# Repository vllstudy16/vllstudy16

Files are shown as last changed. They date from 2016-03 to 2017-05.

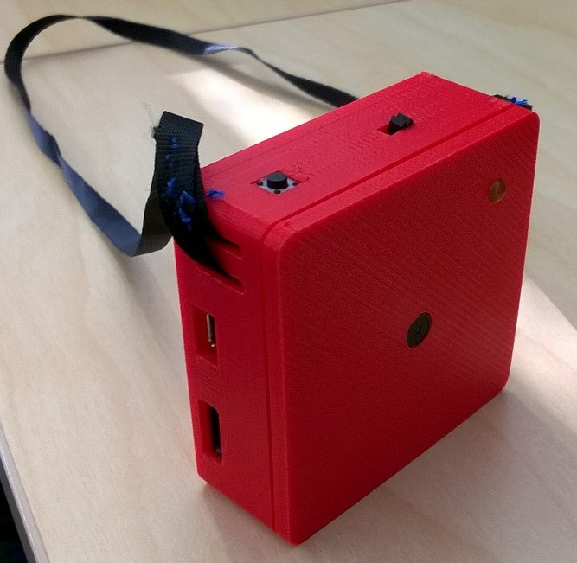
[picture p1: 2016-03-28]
WP_20151012_001.jpg

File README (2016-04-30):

# README

The following files in the repository describe the schematics and build instructions for a wearable camera:

1. CameraBuild-report.pdf : is a technical report on how to build a life logging camera. It details the components used, and the hardware & software tools required to build the camera, along with the description of it’s functionality and some basic debugging points.

2. Camera-schematic.pdf : contains the wiring diagram for the camera.

3. LifeLogging_Camera_serial_0.4.ino : is the arduino code file that makes the camera functional.

4. LifeLoggingCameraV6-base.scad : is a 3D software file, required to build the bottom plastic enclosure of the camera.

5. LifeLoggingCameraV6-base.stl : Created from ‘LifeLoggingCameraV6-base.scad’, file to be used with the 3D printer software for printing the bottom plastic enclosure.

6. LifeLoggingCameraV6-top.scad : is a 3D software file, required to build the top plastic enclosure of the camera.

7. LifeLoggingCameraV6-top.stl : Created from ‘LifeLoggingCameraV6-top.scad’, file to be used with the 3D printer software for printing the top plastic enclosure.

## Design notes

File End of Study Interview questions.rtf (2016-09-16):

End of study focus group questions
These questions are to be used as a guide for an informal short interview (approximately 30minutes) at the end of the study when the participant(s) returns to the lab. The interviews will be audio recorded.
• How was your general experience of using the camera?
o Do you feel like your behaviour changed when you started wearing it?
o Did you get accustomed to wearing the camera?
o What specifically did you do to stop photographs being taken? (e.g. turn off switch, put camera away, etc.)
o Were there times you chose not to wear the camera? If so, what were these occasions?
• How did other people respond to your camera?
o Were there times when you felt you needed to explain what the camera was and why you were wearing it?
o Were there times you thought people should ask about the camera but didn’t?
o Did they ask questions? (or give you funny looks?)
o Did people ask about the camera in particular situations more than others? (e.g. in private settings)
o Did they ask not to be photographed, or display any discomfort?
o For cameras with lights: Did people notice the light on the camera? Did they ask about it?
• Your response to other people
o What did you do in response? Even if they didn’t say anything
o Did these questions change your behaviour at all – such as turning the camera off pre-emptively?
• Deleting
o Have you deleted an image of other participants?
o Have you deleted photos of others you know, but who are not participating in the study?
o Have you deleted photos of strangers?
o And why?
• How did the other camera users in your group behave?
o Did the fact that everyone had cameras make a difference to how you felt/behaved?
▪ How did you feel when you were all wearing the cameras together – eg. at home?
▪ How did you feel when you were all wearing the cameras, but other people were around (not wearing cameras)?
▪ What kinds of conversations did you have with the others about the cameras?
▪ What did you expect each other to do with the photos later?
▪ Did you think about the privacy of each other in the study?

▪ Because you know you are all participating in this study, when would you ever delete a photo of someone else who is signed up to it?
(That is, does being part of the study make some photos more acceptable than they would be normally?)

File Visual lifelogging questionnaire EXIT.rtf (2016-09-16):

Visual life-logging Study
Exit Questionnaire

The following questionnaire asks you for some information about yourself, and asks for your opinions about a range of topics relating to this research. On these latter questions there are no right or wrong answers, please just give your opinion. You are free to omit questions you do not wish to answer.
Participant ID:____________________

Privacy Attitudes Questionnaire
The purpose of this set of questions is to understand your privacy attitudes. Please answer the following eight questions by circling the chosen response.
1. Consumers have lost all control over how personal information is collected and used by companies.
1 2 3 4 5 6 7 8 9
Strongly Neither agree Strongly
disagree nor disagree agree

2. Most businesses handle the personal information they collect about consumers in a proper and confidential way.
1 2 3 4 5 6 7 8 9
Strongly Neither agree Strongly
disagree nor disagree agree

3. Existing laws and organizational practices provide a reasonable level of protection for consumer privacy today.
1 2 3 4 5 6 7 8 9
Strongly Neither agree Strongly
disagree nor disagree agree

4. I am concerned about online identity theft.
1 2 3 4 5 6 7 8 9
Strongly Neither agree Strongly
disagree nor disagree agree

5. I am concerned about my privacy online.
1 2 3 4 5 6 7 8 9
Strongly Neither agree Strongly
disagree nor disagree agree

6. I am concerned about my privacy in everyday life.
1 2 3 4 5 6 7 8 9
Strongly Neither agree Strongly
disagree nor disagree agree

7. I am likely to read the privacy policy of an ecommerce site before buying anything.
1 2 3 4 5 6 7 8 9
Strongly Neither agree Strongly
disagree nor disagree agree
8. Privacy policies accurately reflect what companies do.
1 2 3 4 5 6 7 8 9
Strongly Neither agree Strongly
disagree nor disagree agree
Attitudes towards the privacy of others
• If somebody is not careful about protecting their own privacy, I cannot trust them about respecting mine
1 2 3 4 5 6 7 8 9
Strongly Neither agree Strongly
disagree nor disagree agree

• If I am to enjoy some privacy in my life, I need my friends to be careful about protecting their privacy as well
1 2 3 4 5 6 7 8 9
Strongly Neither agree Strongly
disagree nor disagree agree

• I could never trust someone as my confidant if they go around sharing details about their own private lives
1 2 3 4 5 6 7 8 9
Strongly Neither agree Strongly
disagree nor disagree agree
• The level of privacy that I can enjoy depends on the extent to which people around me protect their own privacy
1 2 3 4 5 6 7 8 9
Strongly Neither agree Strongly
disagree nor disagree agree

• It is important for me to respect the privacy of individuals, even if they are not careful about protecting their own privacy
1 2 3 4 5 6 7 8 9
Strongly Neither agree Strongly
disagree nor disagree agree

• I value other people’s privacy as much as I value mine
1 2 3 4 5 6 7 8 9
Strongly Neither agree Strongly
disagree nor disagree agree

• Even when somebody is not careful about his/her privacy, I do my best to respect that person’s privacy
1 2 3 4 5 6 7 8 9
Strongly Neither agree Strongly
disagree nor disagree agree

• I always do my best not to intrude into other people’s private lives
1 2 3 4 5 6 7 8 9
Strongly Neither agree Strongly
disagree nor disagree agree

• Respect for others’ privacy should be an important priority in social relations
1 2 3 4 5 6 7 8 9
Strongly Neither agree Strongly
disagree nor disagree agree

Questions about including bystanders in life logging
Please rate whether you agree or not with the following statements:
• In non-public spaces, someone using a lifelogging device should have the consent of bystanders to include their photos in lifelogs.

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

• In non-public spaces, it is important that bystanders in the vicinity of someone using a lifelogging device be informed as to what the lifelogging device is doing.

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

• In public spaces, someone using a lifelogging device should have the consent of bystanders to include their photos in lifelogs.

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

• In public spaces, it is important that bystanders in the vicinity of someone using a lifelogging device be informed as to what the lifelogging device is doing.

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

Comfort with life logging
Please rate your comfort with the following services:
• An ‘always on’ system where pictures are automatically and constantly made available to those you have authorized

1 2 3 4 5 6 7 8 9
Not at all comfortable Very comfortable

• Services where you share pictures (taken by yourself or others) deliberately by uploading pictures you want to share and authorizing explicitly who is able to view them

1 2 3 4 5 6 7 8 9
Not at all comfortable Very comfortable

• How comfortable were you in using the life logging camera during this study while in public?

1 2 3 4 5 6 7 8 9
Not at all comfortable Very comfortable

• How comfortable were you in using the life logging camera during this study while in private (e.g. at home)?

1 2 3 4 5 6 7 8 9
Not at all comfortable Very comfortable

• How comfortable were you around others using a life logging camera?

1 2 3 4 5 6 7 8 9
Not at all comfortable Very comfortable

• How interested are you in purchasing and using your own life logging camera in the future (assuming they are affordable)?

1 2 3 4 5 6 7 8 9
Not at all interested Very interested

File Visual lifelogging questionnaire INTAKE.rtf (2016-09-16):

Visual life-logging Study
Intake Questionnaire

The following questionnaire asks you for some information about yourself, and asks for your opinions about a range of topics relating to this research. On these latter questions there are no right or wrong answers, please just give your opinion. You are free to omit questions you do not wish to answer.

Demographics
Participant ID: _____________ Camera number: _____________

Gender: female / male / other

Age: ______
Nationality: _____________________________
Length of time in the UK (if not born here): __________________
What is your degree major? (e.g. Psychology, Law)

What year of university are you in? _____________

Please circle your level of prior experience with the following types of social network sites/apps:
Facebook: Never used / Have used in the past / Have but use infrequently / Use currently
Twitter: Never used / Have used in the past / Have but use infrequently / Use currently
Instagram: Never used / Have used in the past / Have but use infrequently / Use currently
Snapchat: Never used / Have used in the past / Have but use infrequently / Use currently

Please list any other social network sites or apps you currently use:

How often do you share photographs on social media (via any site/app):
1 2 3 4 5 6 7 8 9
Never Monthly Several times a day

If you do share photographs, for which of the following reasons (you can tick multiple reasons):
□ To record and remember that I had visited this place
□ To share the places I visit
□ To share photos of my friends
□ To share what I am doing
□ To share photos of my family
□ To show that I liked the place
□ To appear cool and interesting
□ I wanted geographically distant friends/family to feel that they were part of my day-to-day activities
□ I was at a political/social/artistic event and want to promote it
□ To demonstrate my photography skills
□ To ask for information about something
For what other reasons do you share photos online?
___________________________________________________________________________

How comfortable are you with others tagging you (identifying you) in online photos?
1 2 3 4 5 6 7 8 9
Very uncomfortable Very comfortable

Technology practices
I am familiar with lifelogging or lifeblogging
1 2 3 4 5 6 7 8 9
Not familiar at all Very familiar

Have you ever used any type of life logging camera (i.e. a camera that automatically takes photos throughout the day)?
Yes / No
If yes, what type: ___________________________________________________

Privacy Attitudes Questionnaire
The purpose of this set of questions is to understand your privacy attitudes. Please answer the following eight questions by circling the chosen response.
1. Consumers have lost all control over how personal information is collected and used by companies.
1 2 3 4 5 6 7 8 9
Strongly Neither agree Strongly
disagree nor disagree agree

2. Most businesses handle the personal information they collect about consumers in a proper and confidential way.
1 2 3 4 5 6 7 8 9
Strongly Neither agree Strongly
disagree nor disagree agree

3. Existing laws and organizational practices provide a reasonable level of protection for consumer privacy today.
1 2 3 4 5 6 7 8 9
Strongly Neither agree Strongly
disagree nor disagree agree

4. I am concerned about online identity theft.
1 2 3 4 5 6 7 8 9
Strongly Neither agree Strongly
disagree nor disagree agree

5. I am concerned about my privacy online.
1 2 3 4 5 6 7 8 9
Strongly Neither agree Strongly
disagree nor disagree agree

6. I am concerned about my privacy in everyday life.
1 2 3 4 5 6 7 8 9
Strongly Neither agree Strongly
disagree nor disagree agree

7. I am likely to read the privacy policy of an ecommerce site before buying anything.
1 2 3 4 5 6 7 8 9
Strongly Neither agree Strongly
disagree nor disagree agree

8. Privacy policies accurately reflect what companies do.
1 2 3 4 5 6 7 8 9
Strongly Neither agree Strongly
disagree nor disagree agree

Attitudes towards the privacy of others
If somebody is not careful about protecting their own privacy, I cannot trust them about respecting mine
1 2 3 4 5 6 7 8 9
Strongly Neither agree Strongly
disagree nor disagree agree

If I am to enjoy some privacy in my life, I need my friends to be careful about protecting their privacy as well
1 2 3 4 5 6 7 8 9
Strongly Neither agree Strongly
disagree nor disagree agree

I could never trust someone as my confidant if they go around sharing details about their own private lives
1 2 3 4 5 6 7 8 9
Strongly Neither agree Strongly
disagree nor disagree agree

The level of privacy that I can enjoy depends on the extent to which people around me protect their own privacy
1 2 3 4 5 6 7 8 9
Strongly Neither agree Strongly
disagree nor disagree agree

It is important for me to respect the privacy of individuals, even if they are not careful about protecting their own privacy
1 2 3 4 5 6 7 8 9
Strongly Neither agree Strongly
disagree nor disagree agree

I value other people’s privacy as much as I value mine
1 2 3 4 5 6 7 8 9
Strongly Neither agree Strongly
disagree nor disagree agree

Even when somebody is not careful about his/her privacy, I do my best to respect that person’s privacy
1 2 3 4 5 6 7 8 9
Strongly Neither agree Strongly
disagree nor disagree agree

I always do my best not to intrude into other people’s private lives
1 2 3 4 5 6 7 8 9
Strongly Neither agree Strongly
disagree nor disagree agree

Respect for others’ privacy should be an important priority in social relations
1 2 3 4 5 6 7 8 9
Strongly Neither agree Strongly
disagree nor disagree agree

Relationship to other participants

How long have you known each other?

What is your connection to one another? (e.g. flatmates)

The end, thank you!

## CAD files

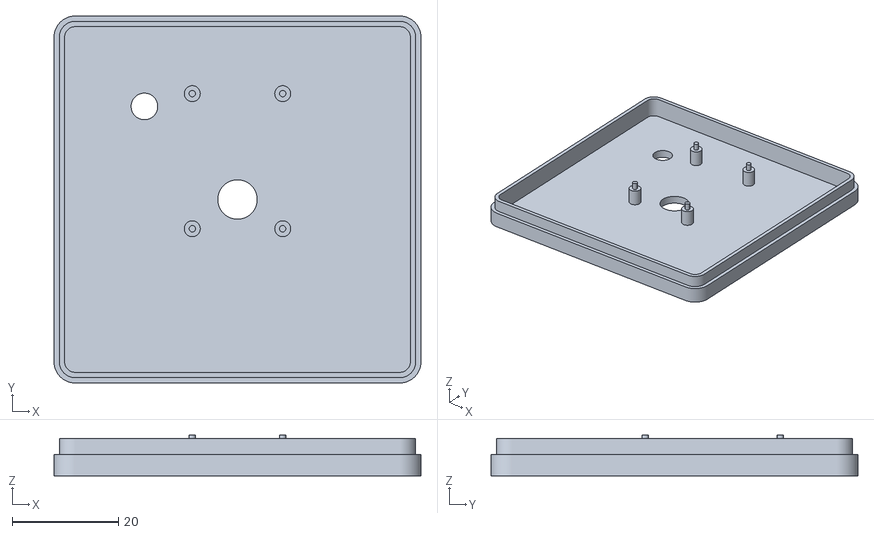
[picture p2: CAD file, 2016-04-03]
LifeLoggingCameraV6-top.stl
69.0 x 69.0 x 7.70

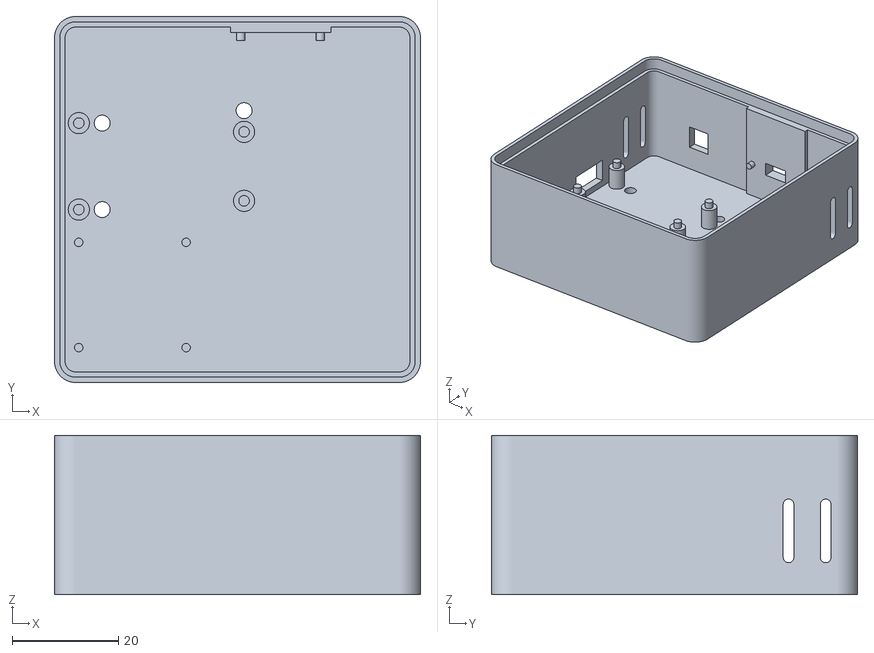
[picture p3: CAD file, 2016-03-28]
LifeLoggingCameraV6-base.stl
69.0 x 69.0 x 30.0

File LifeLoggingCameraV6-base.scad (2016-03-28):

$fs = 0.1; // smoothness of curves in render
$fa = 0.1;

/* Box */
{
    thickness = 2; //wall thickness
    extraThickness = 0.1; // required for proper rendering when $fs is large
    curve = 4; // curve on the edges of the box, must be > thickness
    internalDimensions = [65, 65, 30]; //internal dimensions
    externalDimensions = [internalDimensions[0] + (thickness * 2), internalDimensions[1] + (thickness * 2), internalDimensions[2] + (thickness * 2)];
    bottomHeight = 28; // height of the bottom half of the box
    topHeight = internalDimensions[2] - bottomHeight; // height of the top half of the box
    FR4Thickness = 1.7;
    overlap = 3;
}
//

cameraHolePos = [externalDimensions[0] / 2, externalDimensions[1] / 2];
ledHolePos = [externalDimensions[2] / 2, externalDimensions[1] - (externalDimensions[2] / 2)];
usbHolePos = [-0.01, 31.25 + curve, thickness + FR4Thickness];
sdHolePos = [-0.01, 6.5 + curve, thickness + FR4Thickness];
resetHolePos = [externalDimensions[2] / 2, externalDimensions[1] - (thickness / 2), externalDimensions[2] / 3];
powerHolePos = [externalDimensions[0] * ((sqrt(5) - 1) / 2), externalDimensions[1] - (thickness / 2) - 0.5, externalDimensions[2] / 3];
usbSize = [21.5, 36, 7.2];
sdSize = [25, 31, 3.55];
resetHoleSize = 6;
powerHoleSize = [6.5, thickness + extraThickness + 1, 3.5];
ledHoleRad = 2.5;
cameraHoleRad = 3.7;
cameraStandoffHeight = 4;

{
    /*
loc =   [
            [externalDimensions[0] + 3 , 0, 0],
            [externalDimensions[0] + 3 , 0, 22 + 5 + (thickness * 2)],
            [externalDimensions[0], 0, 22 + 5 + (thickness * 2)],
            [externalDimensions[0], 0, 22 + (thickness * 2)],
            [externalDimensions[0], 0, 22 + 5 + (thickness * 2)],
            [externalDimensions[0] + 3 , 0, 22 + 5 + (thickness * 2)],
            [externalDimensions[0] + 3 , 0, 0],
            [externalDimensions[0] + 3 , 0, 0]
        ];

function xyz(t,i) = 
    lookup(t, [
    [0/len(loc),loc[0][i]],
    [1/len(loc),loc[1][i]],
    [2/len(loc),loc[2][i]],
    [3/len(loc),loc[3][i]],
    [4/len(loc),loc[4][i]],
    [5/len(loc),loc[5][i]],
    [6/len(loc),loc[6][i]],
    [7/len(loc),loc[7][i]],

]);

loc2 =   [
            [0, 0, 0],
            [0, 0, 0],
            [0, -180, 0],
            [0, -180, 0],
            [0, -180, 0],
            [0, 0, 0],
            [0, 0, 0],
            [0, 0, 0]
        ];

function xyz2(t,i) = 
    lookup(t, [
    [0/len(loc2),loc2[0][i]],
    [1/len(loc2),loc2[1][i]],
    [2/len(loc2),loc2[2][i]],
    [3/len(loc2),loc2[3][i]],
    [4/len(loc2),loc2[4][i]],
    [5/len(loc2),loc2[5][i]],
    [6/len(loc2),loc2[6][i]],
    [7/len(loc2),loc2[7][i]],

]);

loc3 =   [
            [0, 0, 0],
            [0, 0, 90],
            [0, 0, 180],
            [0, 0, 270],
            [0, 0, 360],
            [0, 0, 180],
            [0, 0, 0],
            [0, 0, 0]
        ];

function xyz3(t,i) = 
    lookup(t, [
    [0/len(loc3),loc3[0][i]],
    [1/len(loc3),loc3[1][i]],
    [2/len(loc3),loc3[2][i]],
    [3/len(loc3),loc3[3][i]],
    [4/len(loc3),loc3[4][i]],
    [5/len(loc3),loc3[5][i]],
    [6/len(loc3),loc3[6][i]],
    [7/len(loc3),loc3[7][i]],

]);
*/
}
//

module cylinderHull(a, r)
{
    hull()
        {
            cylinder(r = r, h = a[2]);
            translate([a[0], 0, 0]) 
                cylinder(r = r, h = a[2]);
            translate([0, a[1], 0]) 
                cylinder(r = r, h = a[2]);
            translate([a[0], a[1], 0]) 
                cylinder(r = r, h = a[2]);
        }
}
//

module box(height, lip)
{
    // 0 = outer lip, 1 = inner lip
    translate([curve, curve, 0]) difference() 
    {
        union()
        {
            cylinderHull([externalDimensions[0] - (curve * 2), externalDimensions[1] - (curve * 2), height + thickness], curve);
            if(lip == 1)
            {
                translate([0, 0, thickness]) 
                    cylinderHull([externalDimensions[0] - (curve * 2), externalDimensions[1] - (curve * 2), height + overlap],curve - (thickness / 2));
            }
        }
        {
            translate([0, 0, thickness]) 
                cylinderHull([externalDimensions[0] - (curve * 2), externalDimensions[1] - (curve * 2), height + thickness + overlap], curve - thickness);
            if(lip == 0)
            {
                translate([0, 0, height + thickness - overlap]) 
                    cylinderHull([externalDimensions[0] - (curve * 2), externalDimensions[1] - (curve * 2), 0.01 + overlap], curve - (thickness / 2));
            }
        }
    }
}
//
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

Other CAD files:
LifeLoggingCameraV6-top.scad

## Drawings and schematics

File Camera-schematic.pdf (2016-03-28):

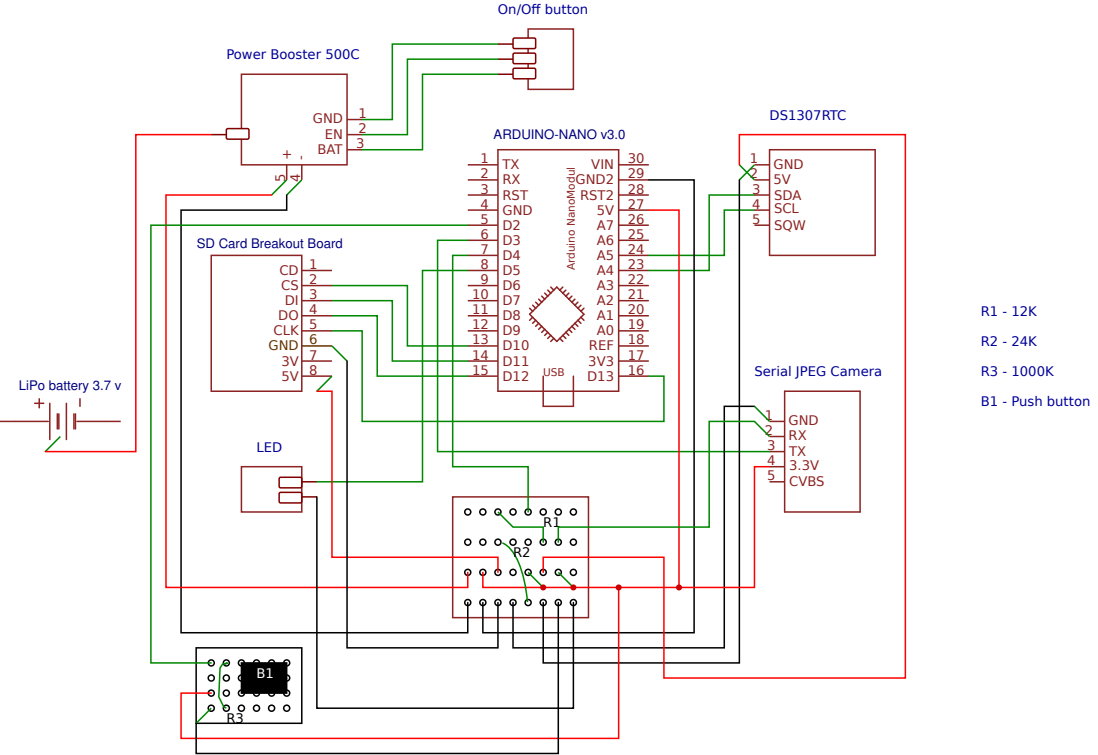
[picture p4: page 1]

SD Card Breakout Board

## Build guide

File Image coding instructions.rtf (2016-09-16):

Image content analysis –
Instructions for coders
Guidelines:
• It is ok to make inferences based on previous photos in a sequence (e.g. if you can tell that they are in the same room)
• We will not code what position the camera appears to be in (only what is in the photo)
Codes:
• Activity type (if apparent) - e.g. eating, walking, watching tv, studying; or if none: no discernible objects
• Number of other people present
• Number of faces visible and invisible
o We code the face of a person in a photo as “invisible”, if:
▪ the face of that person is fuzzy due to distance of that person from the camera or due to the resolution of the camera, or
▪ the face of the person is covered or that person is not facing the camera, or
▪ the face of that person is not in the photo.
• Activity that other people in photos appear to be doing
• Do they appear to be interacting with the camera wearer or not?
o Based on proximity and orientation to camera (close and facing the camera)
o This can be inferred from previous photos
• Is the photo a selfie?
o yes if the participant was either standing in front of a mirror, or if they seemed to have turned the camera to face them. If they just have an arm or something in shot, this is not a selfie.
• Indoors/outdoors: “outdoors” or “indoors” or “unknown”
• Location: in addition to outdoors/indoors, if possible label where they are (e.g. a bedroom, kitchen, park, café, etc). If unclear, code as unclear
• Presence of computer/phone/tablet screen. If the computer/phone/tablet screen is closed, code that image as “yes (closed)”. If the screen in the photo is turned on but fuzzy code that photo as “yes (fuzzy)”.
• Presence of participant, and if yes what part of them (e.g. hand)
• Presence of another camera wearer/camera: yes or no
• Presence of identifying object: e.g. ATM/Card machine or id card, visible photographs of people: yes or no
• Presence of documents or writing – e.g. on paper, printout, book (not photographs): yes, yes (fuzzy) or no
• Alcoholic beverages/cigarettes/other vices visible: yes or no
• Food and drink: glass, plates, etc are included even if empty. Does not include queuing for food.
• Any other unusual/interesting detail – such as people in embarrassing moments (open ended text)

Instructions for keeping coding consistent so we can analyse it categorically:
• For image name just put it without the .jpg extension (so we can match with the image reviewing software data)
• Use YYYYMMDD date format in the date column
• Don’t put remarks, question marks, extra details in any column except the ‘other detail’ column at the end
• Try to use the same consistent codes each time – e.g. “walking” rather than “walk” or “walking down street” etc
• Use “unclear” as the code for anything that is indiscernible, blurry, etc, or unknown if you cannot tell if they are indoors or outdoors
• Don’t put anything other than numbers in the columns where you count people present (e.g. don’t use >4, if unsure just put the number you can make out)
• If you think the person in the photo might be the participant, put Y in the selfie column. The recruiting researcher will confirm this.
• If any of these columns you are not sure about, probably best to put NO.

Calculating Kappa
Because we are using different combinations of coders, we need to use Fleiss Kappa (see https://statistics.laerd.com/spss-tutorials/cohens-kappa-in-spss-statistics.php - we violate assumption #5).
We can only calculate this on categorical fields (e.g. yes/no), which for us are:
• Selfie
• Others interacting
• Outdoors/indoors
• Presence of screen
• Presence of participant
• Presence of another participant
• Identifying object
• Documents
• Alcohol/cigarettes/other vices
• Food and drink
Fleiss Kappa was calculated in R using the IRR package (https://cran.r-project.org/web/packages/irr/index.html).

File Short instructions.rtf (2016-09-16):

Visual life-logging study

How to handle the camera
• The camera takes photographs every 5 minutes
• You can delete the last 5 minutes of photographs by pressing the delete button on the camera (or later when reviewing the photos in the evening)
• Please charge the camera every day
• The camera should tolerate a very light rain shower but anything heaver please try to keep it dry (put inside clothing if heavy rain).
• To stop the camera taking photos either turn it off or put it away (e.g. in your pocket)
• If anything happens to your camera (e.g. it is stolen or breaks) please alert us as soon as possible. Please do not try to fix it yourself.

Photography rules

We ask that you respect the laws and guidelines around public photography. In particular you must:
• Respect rules about taking photographs in public places (e.g. if you see a “no photography allowed” sign).
• Respect other people’s wishes to not be photographed. If anyone objects to you wearing the camera in their presence then put it in your pocket. If anyone asks that a photo of them be deleted simply press the delete button. When you review the photos if you see an image of someone who requested that you not photograph them please delete it at that time.
• Please delete photographs with any nudity. It is specifically prohibited to keep (or share) photographs of naked people or photographs that would otherwise compromise an individual’s safety or reputation.
• If you observe other members participating in this study using the technology inappropriately or illegally, please get in contact with the researcher.

Short version daily photograph review instructions
• To run the image reviewer software you will need Java 8 installed on your computer (https://java.com/en/download/)
• Take the SD card out of the camera and put it in your card reader (usb stick), then plug the card reader into your computer
• Open the image reviewer software and select the folder that contains your photos from the day
• After a moment the photos will load, and you can step through the instructions – first deleting photographs as you wish (these will be permanently deleted), and then completing all of the rating questions
• At the end of the program you will be able to save your responses to the same folder as the images, on the SD card.
• Please do not modify file/folder names, or delete any files (except through the app).
• Remember to put the SD card back into the camera, ready for the next day.
If you would like assistance, or have any questions or problems please do not hesitate to contact <<redacted>>>

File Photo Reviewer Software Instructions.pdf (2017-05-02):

## To Charge the Camera

Turn off the camera first (left as you look down at it with the camera facing forward). Plug the camera into your computer with the cable provided.

## Photo Reviewer Software Instructions

1. To review the photos: Take the SD card out of the camera and plug it into the Micro SD USB stick. Then put the USB stick into your computer. It should appear as a device on your computer.
2. Double click on the Photo Reviewer software icon (PhotoReviewer.jar) – in the main directory of the SD card.
3. If you do not have Java 8 installed on your computer you will receive an error message. Please install the latest update from https://java.com/en/download/.
4. The application should launch and you will be presented with a button to load the photos.

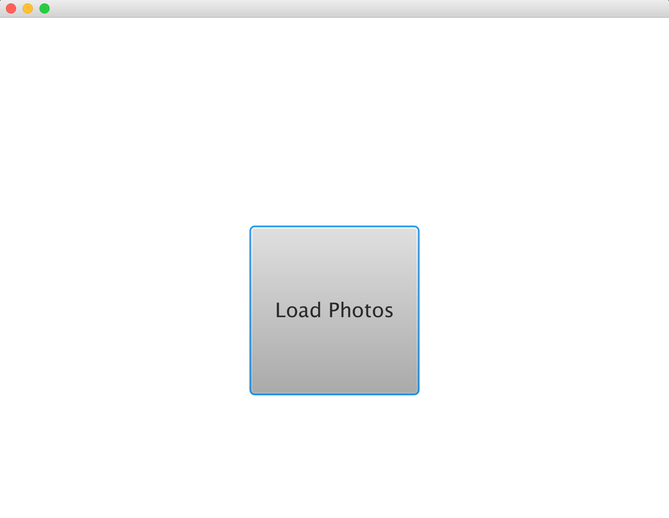
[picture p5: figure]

5. Clicking the “Load Photos” button presents a directory selection dialogue. Navigate to the SD card on the camera and select the date which you wish to review and select “Open”.

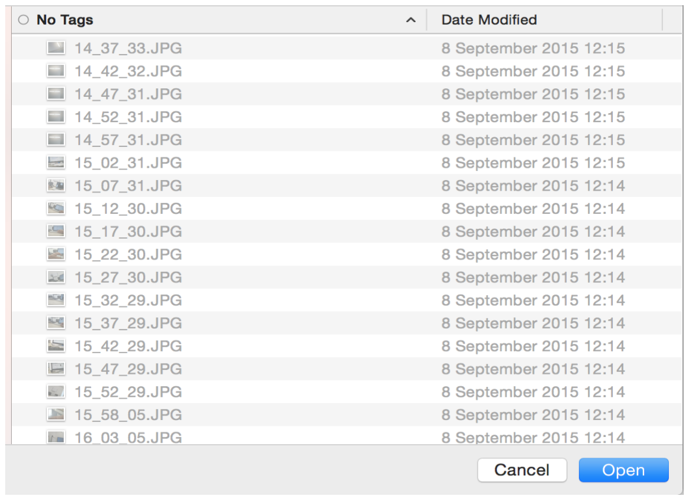
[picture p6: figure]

6. Complete the instructions on each screen clicking the “Next” button.
7. When you have completed all the tasks the final screen will be shown asking you to “Save”

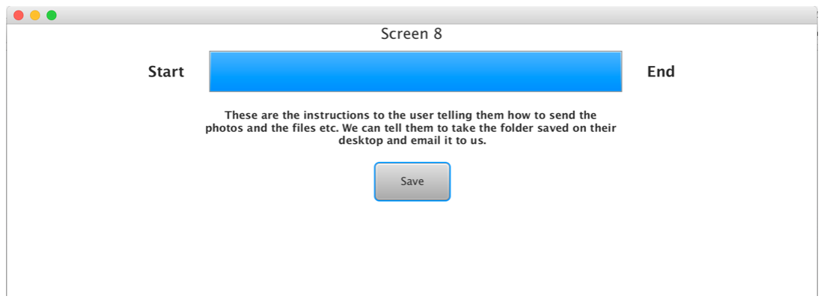
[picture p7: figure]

8. Select the same folder the photos came from (i.e. today’s photos).
9. The software will save a results file in the directory you specified.
10. Please keep it on the SD card. You can also email the files to <researcher>
11. Once saved you can now close the Photo Reviewer software. Just click the close/cross button.
12. Eject the SD card and put it back in the camera.
13. Leave the camera charging overnight, and then unplug it and switch it back on in the morning. You should see the light flash for a few seconds after you switch the camera on.

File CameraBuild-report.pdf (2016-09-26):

## Technical Report: How to Build a Life-Logging Camera

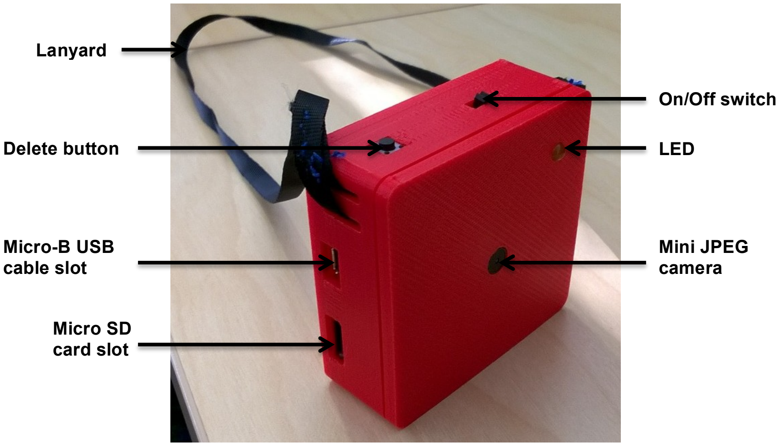
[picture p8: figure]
Delete button; Mini JPEG camera; Micro SD card slot; Micro-B USB cable slot; LED; Lanyard; On/Off switch

We built a wearable and programmable camera with the following components packed together in a 3d printed plastic box of size 65*65*22 mm.
1. Adafruit Real time clock – DS1307 breakout kit
2. Arduino nano v3.0 micro-controller
3. Adafruit Micro SD breakout board
4. Adafruit Mini JPEG Camera
5. Adafruit PowerBoost 500C
6. Resistors (12k, 24k, 1000k)
7. LiPoly battery 2000mAh
8. Micro-B USB cable
9. Micro SD card
10.Push Button
11.Slide button
12.Veroboard
13.Lanyard
14.Wires
15.LED

Following tools are needed for building the camera unit. Hardware:
1. Soldering Machine
2. Heat gun
3. Glue gun
4. Cutter
5. Foreceps
6. 3d printer
Software:
1. Arduino
2. OpenSCAD

With the help of these tools, we solder the components together (as per the diagram below) glue them and fit in the 3d printed plastic box.

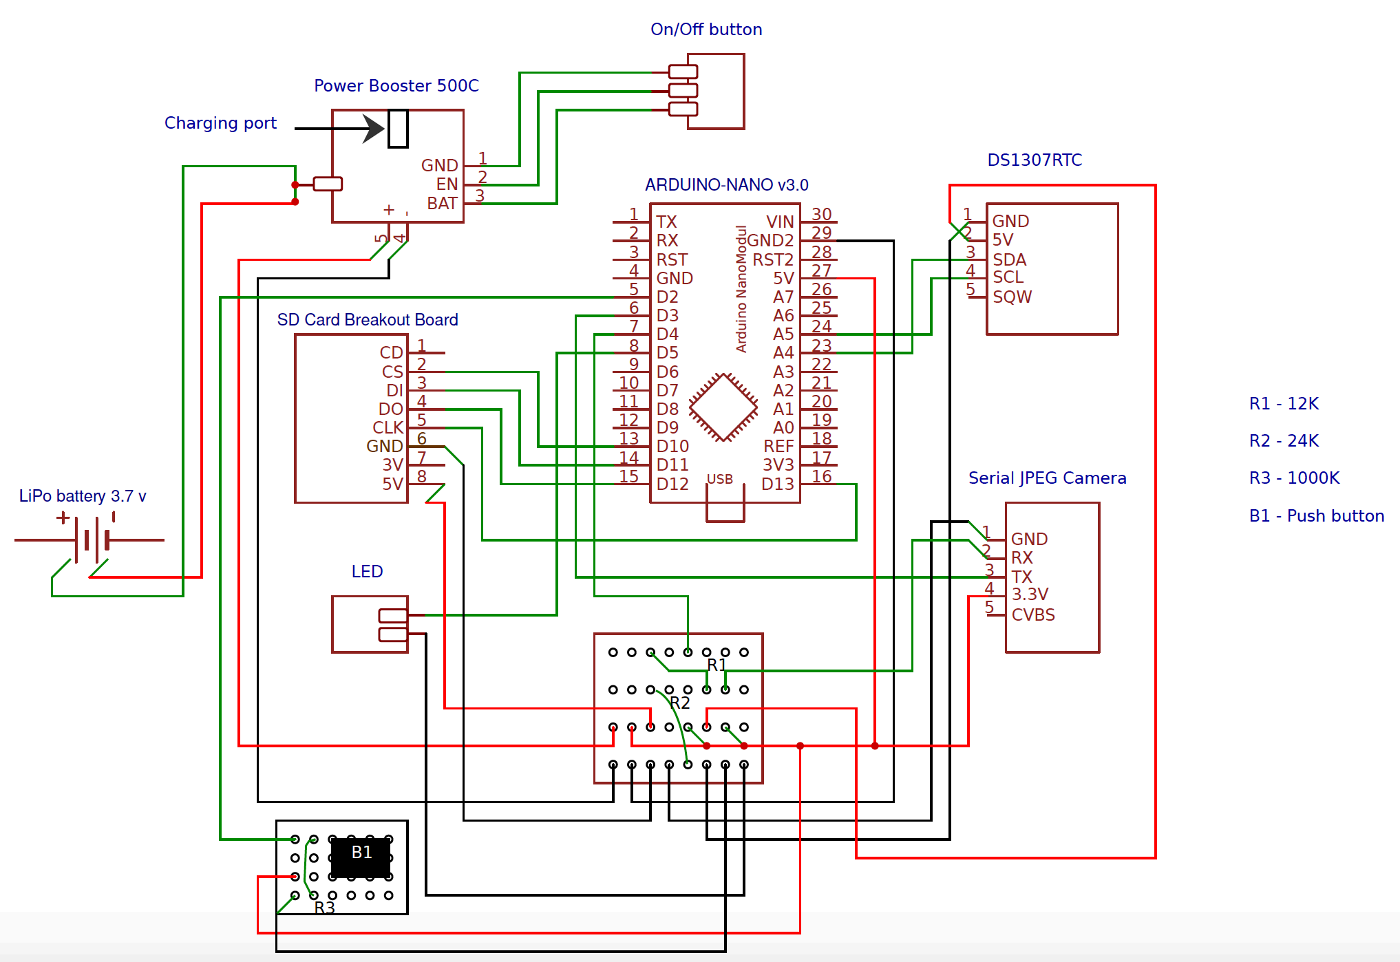
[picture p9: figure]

A user can wear the camera around their neck and move around. The LED flashes when the wearable camera is switched on. It takes automatic pictures of size 640*480 pixels and stores them in the micro SD card. The software program running on the arduino microcontroller creates different directories for each day, each storing pictures taken on that particular day. Photos are stored with the naming convention: <hour_minutes_seconds> and are taken randomly with a gap of at-least 5 minutes. Some more features of the life-logging camera are:

1. On/Off sliding button: to switch the camera on/off.
2. Push button: to delete photos taken in last 5 minutes.
A file named “del_log.txt “ records the photos that have been deleted.
3.“Random flashes in between” mode: Switch on the camera with push button in pressed state. The flash blinks randomly with a gap of at-least 15 minutes. 2 consecutive flashes occur with each of 0.5 seconds duration.
A file named “fla_log.txt” records the start and end flash time, throughout the time that camera is on.
4.“No random flashes in between” mode: Switch on the camera. No flashes thereafter.
5. When connected to power, the camera will always be on. The on/off button would not work in that scenario.
6. The LED will lit up permanently and the camera won’t work, if there is no memory card.
7.The wearable camera runs on a 2000 m Ah LiPo battery. It can effectively work for entire day and then needs to be charged overnight through the micro USB slot provided.
The | source | code | and | 3D | file | for | the | camera | case | can | be | found | at:
https://github.com/vllstudy16/vllstudy16

Basic Debugging:
1. Make the hardware connections as per the diagram. They should be strong and well soldered. Make sure that no connection is broken or accidentally touching other connection.
2. If the LED doesn’t glow, it is possible that it’s connected the wrong way. Just exchange the wire connections.

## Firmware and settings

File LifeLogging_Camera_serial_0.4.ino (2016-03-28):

#include <Adafruit_VC0706.h>
#include <SPI.h>
#include <SD.h>
#include <SoftwareSerial.h>
#include <TimerOne.h>
#include <Wire.h>
#include <RTClib.h>
#include <EEPROM.h>

#define chipSelect 10
#define cameraTX 3
#define cameraRX 4
#define switchPin 2
#define ledPin 5

//ms betwen photos
#define photoDelayLength 300000 //15 min
//length in us of flashes
#define flashLength 500000 //0.5 sec
//minimum length of on period (length of time on / length of flash)
#define onPeriodMin 10 //5 sec
//maximum length of on period (length of time on / length of flash)
#define onPeriodMax 10 //5 sec
//minimum length of off period in sec
#define offPeriodMin 900 //15 min
//maximum length of off period in sec
#define offPeriodMax 900 //15 min
//amount of time to delete when button is pressed in sec
#define deleteLength 335 //5 min + extra to make sure last photo deleted

SoftwareSerial cameraconnection = SoftwareSerial(cameraTX, cameraRX);
Adafruit_VC0706 cam = Adafruit_VC0706(&cameraconnection);

RTC_DS1307 rtc;

boolean deletePhotoToggle = false;
boolean flashStartToggle = false;
boolean flashEndToggle = false;
boolean flash = false;
char dirName[10] = {"/00000000"};
uint32_t offRandom = 30; //start flashing after 30 sec
uint16_t onRandom = 0;
DateTime flashStart;
DateTime flashEnd;

void setup()
{
	randomSeed(analogRead(0));

	pinMode(ledPin, OUTPUT);
	PORTD |= (1 << ledPin); //set ledPin high
  
	pinMode(switchPin, INPUT);

	Serial.begin(9600);
	Wire.begin();
  rtc.begin();
	
	Serial.println(F("-----------------------"));
	Serial.println(F("LifeLogging Camera"));
	Serial.println(F("-----------------------"));
	Serial.println();

	if (EEPROM.read(0) == 0)
	{
		flash = false;
	}
	else
	{
		flash = true;
	}

	if (digitalRead(switchPin) == HIGH)
	{
		flash = !flash;
		EEPROM.write(0, flash);

		Serial.print(F("Flashing "));
		Serial.println(flash);
		Serial.println();
	}
  
	// see if the card is present and can be initialized:
	if (!SD.begin(chipSelect))
	{
		Serial.println(F("Card failed, or not present"));
		while(1);
	}
	
	// Try to locate the camera
	if (!cam.begin())
	{
		Serial.println(F("No camera found?"));
		while(1);
	}

	if (!rtc.begin())
	{
		Serial.println(F("RTC is not running"));
		while (1);
	}

	//rtc.adjust(DateTime(__DATE__, __TIME__));
  DateTime now = rtc.now();
  Serial.println(now.year());

	if (now.year() == 2165)
	{
		Serial.println(F("RTC communication error"));
		while (1);
	}

	// Set the picture size - 640x480
	cam.setImageSize(VC0706_640x480);

	if (flash == false)
	{
		delay(500);
		PORTD &= ~(1 << ledPin); //set ledPin low
		delay(500);
		PORTD |= (1 << ledPin); //set ledPin high
		delay(500);
	}
	else
	{
		offRandom += now.unixtime();

		Timer1.initialize(flashLength);

		delay(500); //gives components time to start
	}

	PORTD &= ~(1 << ledPin); //set ledPin low

	attachInterrupt(0, deletePhotos, FALLING);
}

void loop()
{
	int32_t timeElapsed =  millis();
	Serial.flush();
	dirGen();
	if (flash == true)
	{
		blinkGenerator();
	}
	takePhoto(timeElapsed);
	deleteBuffer();
	if (flash == true)
	{
		storeFlashTime();
	}

	while((millis() - timeElapsed) < photoDelayLength);
}

void takePhoto(int32_t timeElapsed)
{
	uint32_t timeDifference = 0;
	char charBuff[23];
	strlcpy(charBuff, fileNameGen(rtc.now()), sizeof(charBuff));

	if (!cam.takePicture())
	{
		Serial.println(F("Failed to take photo"));
		return;
	}
	else
	{
		Serial.println(F("Picture taken"));
	}
		
	if (SD.exists(charBuff))
	{
		Serial.println(F("Overwriting"));
	}

	// Open the file for writing
	File imgFile = SD.open(charBuff, FILE_WRITE);

	// Get the size of the image (frame) taken  
	uint16_t jpglen = cam.frameLength();
	Serial.print(F("Writing image to "));
	Serial.println(charBuff);
	Serial.print(F("Storing "));
	Serial.print(jpglen, DEC);
	Serial.print(F(" byte image."));

	pinMode(8, OUTPUT);
	// Read all the data up to # bytes!
	byte wCount = 0; // For counting # of writes
	while (jpglen > 0)
	{
		// read 32 bytes at a time;
		uint8_t *buffer;
		uint8_t bytesToRead = min(64, jpglen); // change 64 to 32 if storing photos proves unstable
		buffer = cam.readPicture(bytesToRead);
		imgFile.write(buffer, bytesToRead);
		if (++wCount >= 64)
		{
			//Every 2K, give a little feedback so it doesn't appear locked up
			Serial.print('.');
			wCount = 0;
		}
		jpglen -= bytesToRead;
	}
	imgFile.close();

	timeDifference = millis() - timeElapsed;
	Serial.println(F("done!"));
	Serial.print(timeDifference);
	Serial.println(F(" ms elapsed"));
	Serial.println();
	cam.resumeVideo();
}

void logInitialization(char logName[], char title[])
{
	File logFile = SD.open(logName, FILE_WRITE);
	delay(10);
	/*
	logFile.println(F("-------------------------"));
	logFile.println(F("LifeLogging Camera"));
	logFile.print(title);
	logFile.print(F(" Log file "));
	logFile.print(dirName);
	logFile.println();
	logFile.println(F("-------------------------"));
	*/
	logFile.close();
}

void storeFlashTime()
{
	if ((flashStartToggle * flashEndToggle) == true)
	{
		Serial.println(F("Updating fla_log.txt"));
		char charBuff[23];

		strlcpy(charBuff, dirName, sizeof(charBuff));
		strcat(charBuff, "/fla_log.txt");
		File flashLog = SD.open(charBuff, FILE_WRITE);
		strcpy(charBuff, timeNameGen(flashStart));
		flashLog.print(charBuff);
		flashLog.print(F("		"));
		strcpy(charBuff, timeNameGen(flashEnd));
		flashLog.println(charBuff);
		flashLog.close();

		flashStartToggle = false;
		flashEndToggle = false;
	}
}

void blinkLED()
{
	if (digitalRead(ledPin) == HIGH)
	{
		PORTD &= ~(1 << ledPin); //set ledPin low
	}
	else
	{
		PORTD |= (1 << ledPin); //set ledPin high
	}
	--onRandom;
	if (onRandom == 0)
	{
		flashEndToggle = true;
		PORTD &= ~(1 << ledPin); //set ledPin low
		Timer1.detachInterrupt();
	}
}

void blinkGenerator()
{
	if ((flashStartToggle + flashEndToggle) == 0)
	{
		uint16_t onRandomTemp = onRandom;
		DateTime timeTemp = rtc.now();

		if (onRandomTemp == 0)
		{	
			if (offRandom == 0)
			{
				offRandom = random(offPeriodMin, (offPeriodMax + 1));
				offRandom += timeTemp.unixtime();
			}
			if (offRandom <= timeTemp.unixtime())
			{
				flashStart = timeTemp;
				flashStartToggle = true;
				onRandomTemp = random(onPeriodMin, (onPeriodMax + 1));
				flashEnd = ((onRandomTemp * flashLength) / 1000000) + timeTemp.unixtime();
				offRandom = 0;
				noInterrupts();
				onRandom = onRandomTemp;
				Timer1.attachInterrupt(blinkLED);
				interrupts();
			}
		}
	}
}

void deletePhotos()
{
	deletePhotoToggle = true;
	detachInterrupt(0);
}

void deleteBuffer()
{
	noInterrupts();
	boolean deletePhotoToggleTemp = deletePhotoToggle;
	interrupts();

	if (deletePhotoToggleTemp == true)
	{
		DateTime now = rtc.now();
		uint32_t startTime = now.unixtime();
		char charBuff[23];

		Serial.println(F("Updating del_log.txt"));
		strlcpy(charBuff, dirName, sizeof(charBuff));
		strcat(charBuff, "/del_log.txt");
		File deleteLog = SD.open(charBuff, FILE_WRITE);
		uint32_t x = 0;
		if (startTime > deleteLength)
		{
			x = (startTime - deleteLength);
		}

		while (x < startTime)
		{
			now = x;
			strlcpy(charBuff, fileNameGen(now), sizeof(charBuff));
			if (SD.exists(charBuff))
			{
				Serial.print(F("Deleting "));
				Serial.println(charBuff);
				SD.remove(charBuff);
				deleteLog.println(now.unixtime());
				//deleteLog.println(charBuff);
			}
			++x;
		}
		deleteLog.close();
		deletePhotoToggleTemp = false;
		noInterrupts();
		deletePhotoToggle = false;
		interrupts();
		attachInterrupt(0, deletePhotos, FALLING);
	}
}

char* fileNameGen(DateTime time)
{
	char charBuff[23];
	strlcpy(charBuff, dirName, sizeof(charBuff));
	strcat(charBuff, "/");
	strcat(charBuff, timeNameGen(time));
	strcat(charBuff, ".JPG");
	return charBuff;
}

char* timeNameGen(DateTime time)
{
	char charBuff[9];
	char charShort[3];

	sprintf(charShort, "%d", time.hour());
	if (time.hour() < 10)
	{
		strlcpy(charBuff, "0", sizeof(charBuff));
		strcat(charBuff, charShort);
	}
	else
	{
		strlcpy(charBuff, charShort, sizeof(charBuff));
	}

	strcat(charBuff, "_");

	sprintf(charShort, "%d", time.minute());
	if (time.minute() < 10)
	{
		strcat(charBuff, "0");
		strcat(charBuff, charShort);
	}
	else
	{
		strcat(charBuff, charShort);
	}

	strcat(charBuff, "_");

	sprintf(charShort, "%d", time.second());
	if (time.second() < 10)
	{
		strcat(charBuff, "0");
		strcat(charBuff, charShort);
	}
	else
	{
		strcat(charBuff, charShort);
	}

	return charBuff;
}

char* dateNameGen(DateTime now)
{
	char charBuff[10] = {"\0"};
	char charShort[5];
	strlcpy(charBuff, "/", sizeof(charBuff));

	sprintf(charShort, "%d", now.year());
	if (now.year() < 10)
	{
		strcat(charBuff, "000");
		strcat(charBuff, charShort);
	}
	else if (now.year() < 100)
	{
		strcat(charBuff, "00");
		strcat(charBuff, charShort);
	}
	else if (now.year() < 1000)
	{
		strcat(charBuff, "0");
		strcat(charBuff, charShort);
	}
	else
	{
		strcat(charBuff, charShort);
	}

	sprintf(charShort, "%d", now.month());
	if (now.month() < 10)
	{
		strcat(charBuff, "0");
		strcat(charBuff, charShort);
	}
	else
	{
		strcat(charBuff, charShort);
	}

	sprintf(charShort, "%d", now.day());
	if (now.day() < 10)
	{
		strcat(charBuff, "0");
		strcat(charBuff, charShort);
	}
	else
	{
		strcat(charBuff, charShort);
	}

	return charBuff;
}

void dirGen()
{
	char charBuff[23];
	strlcpy(charBuff, dateNameGen(rtc.now()), sizeof(charBuff));
	if (dirName != charBuff)
	{
		strlcpy(dirName, charBuff, sizeof(dirName));
		if (!SD.exists(dirName))
		{
			SD.mkdir(dirName);
			strlcpy(charBuff, dirName, sizeof(charBuff));
			strcat(charBuff, "/del_log.txt");
			logInitialization(charBuff, "Deleted Files");
			strlcpy(charBuff, dirName, sizeof(charBuff));
			strcat(charBuff, "/fla_log.txt");
			logInitialization(charBuff, "Flash Timings");
			/*
			File flashLog = SD.open(charBuff, FILE_WRITE);
			delay(10);
			flashLog.println(F("ON\t\t\t\t\tOFF"));
			flashLog.close();
			*/
		}
	}
}

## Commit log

2016-09-26 Updated report with corrected schematic
2016-10-16 Coding and Chi Square analysis
    [Coding and Chi Square analysis.xlsx]
2017-08-29 Anonymised intake and exit data
    [Merged intake and exit data 0803_anonymised.csv]
